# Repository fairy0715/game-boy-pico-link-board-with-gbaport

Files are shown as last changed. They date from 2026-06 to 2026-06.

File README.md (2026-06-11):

# USB TO GAMEBOY LINK CABLE ADAPTER

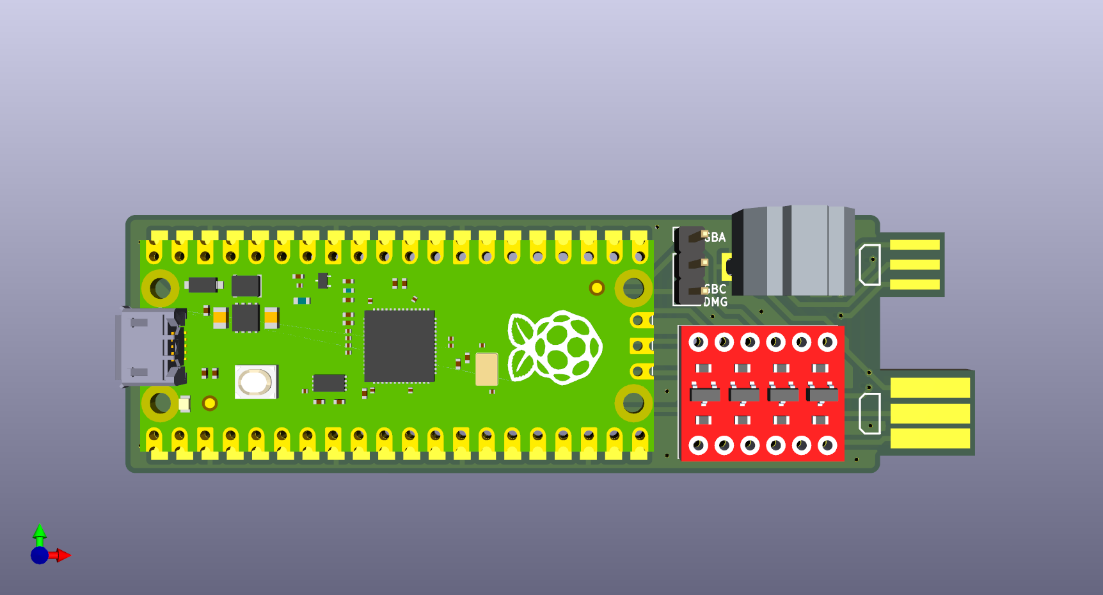
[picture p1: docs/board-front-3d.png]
Board 3D Render


フォーク元の基板にGBA用通信ポートを追加しました、基板を傷めずに接続できます。  
以下はフォーク元のREADMEを追記・修正して作成しています

ライセンスは自作した[libraries/gba_linkport Libraries](libraries/gba_linkport%20Libraries)内のみ[CC0](http://creativecommons.org/publicdomain/zero/1.0/deed.ja)です。  
その他はMITライセンスを引き継いでいます。

Raspberry Pi Pico用のオープンソースUSB-ゲームボーイリンクケーブルアダプタです。入手しやすくはんだ付けしやすい部品で設計されています。

stacksmashing の Gameboy Link adapter に基づいています: https://www.youtube.com/watch?v=KtHu693wE9o

## 回路図

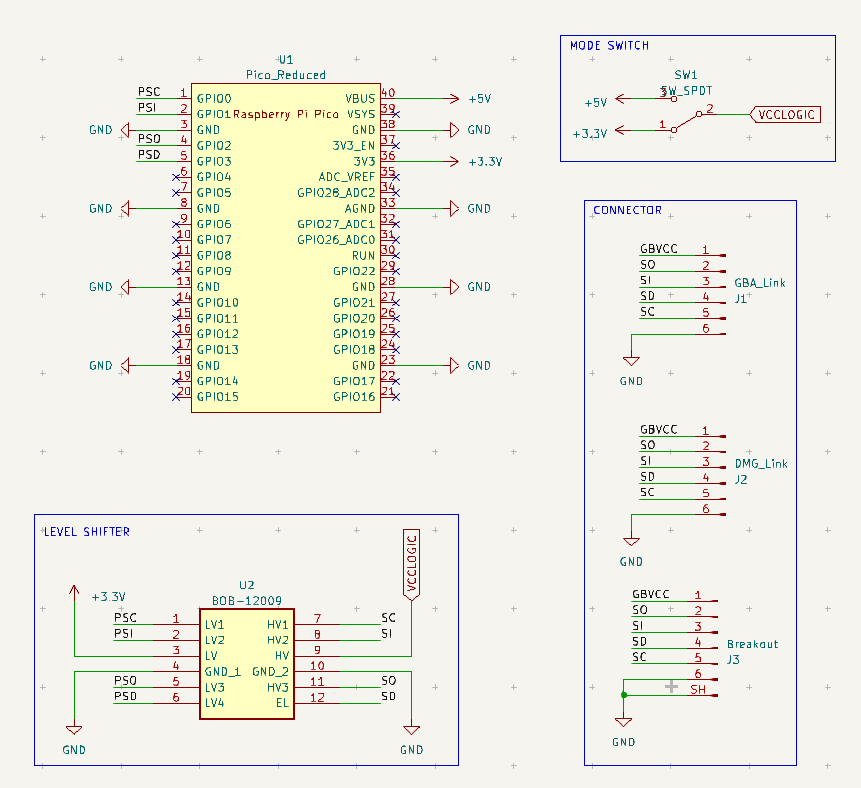
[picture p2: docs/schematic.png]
Schematic


## 部品

|リファレンス|型番|説明|
|---|---|---|
|U1|[Raspberry Pi Pico](https://www.raspberrypi.com/products/raspberry-pi-pico/)|クローン品も互換性あり|
|U2|BOB-12009 [sparkfun](https://www.sparkfun.com/products/12009) [秋月電子（未検証）](https://akizukidenshi.com/catalog/g/g113837/)|Sparkfun 双方向ロジックコンバータ（クローン品も互換性あり）|
|SW1|SS12D00-G3 [amazon](https://www.amazon.com/Tnuocke-Vertical-Position-Switches-SS12D00-G3/dp/B099MRCDG8) [秋月電子](https://akizukidenshi.com/catalog/g/g115707/)|1回路2接点 2.54mmピッチ スライドスイッチ|

SW1 はピンヘッダとジャンパで代用できます

|リファレンス|型番|説明|
|---|---|---|
|SW1|[ピンヘッダ](https://www.amazon.com/dp/B07PKKY8BX)|1x3 2.54mm オスピンヘッダー|
|-|[ジャンパ](https://www.amazon.com/dp/B077957RN7)|2.54mm ジャンパピン、古いマザーボードまたはハードドライブから取り出してください|

添付のリンクは参考用です。同等の部品であればどれでも使用できます。  
秋月電子のレベルシフタは、部品実装面が基板側に来るように配置が必要だと思います。

[テスト済み部品一覧](COMPONENTS.md)

## 基板の注文

基板のデータはリリース内の`gerbers.zip`を使用するか、Kicadファイルから生成してください。[JLCPCB](https://jlcpcb.com/)や[PCBWay](https://www.pcbway.com/)などで注文できます。

ソルダーマスクとシルクスクリーンの色は自由です。  
以下はGBAコネクタを使用せず、直接基板に通信ケーブルを繋ぐ場合の注意点です。

- 基板の厚みは 1.2mm を指定
- 表面処理は ENIG（金メッキ）を推奨

## 基板の組み立て

1. ヤスリなどを使って、基板上のコネクタ部の幅を適切なサイズにカットする
1. Raspberry Pi Picoとレベルシフタモジュールを基板にはんだ付けする（適宜ピンヘッダを使用する）
1. ニッパーで余分なピンを切り落とす
1. スイッチ or ピンヘッダ+ジャンパをはんだ付けする
1. Raspberry Pi Picoにファームウェアを書き込む（[互換性](#互換性) を参照）

## 使い方

GB/GBCソフトの場合はジャンパピンをDMG/GBC側に、GBAソフトの場合はジャンパピンをGBA側に取り付けてください。

>[!WARNING]
>ゲームボーイ/ゲームボーイカラーモードは5Vロジックを使用し、ゲームボーイアドバンスモードは3.3Vロジックを使用することに注意してください。損傷を防ぐため、ジャンパが正しい側に接続されていることを確認してください。

その後 Raspberry Pi Pico を PC に接続し、通信ポート or 基板のコネクタとゲームボーイ（シリーズ）を通信ケーブルで接続してください。

## 互換性

この基板は以下のファームウェアと互換性があります。
- https://github.com/Lorenzooone/gb-link-firmware-reconfigurable （推奨ファームウェア）
- https://github.com/stacksmashing/gb-link-firmware
- https://github.com/stacksmashing/gb-link-printer
- https://github.com/Lorenzooone/PokemonGB_Online_Trades
- https://github.com/dj505/GBPrinterEmu
- https://github.com/Squaresweets/GBPrinter-discord-bot
- https://github.com/KuestenKeks/pc-to-gb-printer

若干の変更を加えることで、以下のような他のファームウェアとも互換性があるはずです。
- https://github.com/untoxa/pico-gb-printer

## 参考

- Raspberry Pi Pico Footprint: https://github.com/ncarandini/KiCad-RP-Pico
- Logic Level Converter (BOB-12009) Footprint: https://www.snapeda.com/parts/BOB-12009/SparkFun%20Electronics/view-part/
- Gameboy Link Connector Footprint: https://github.com/Palmr/gb-link-cable
- 1.2mm PCB Thickness, based on: https://hackaday.io/project/12932-game-link-online/log/43999-received-the-breakout-boards

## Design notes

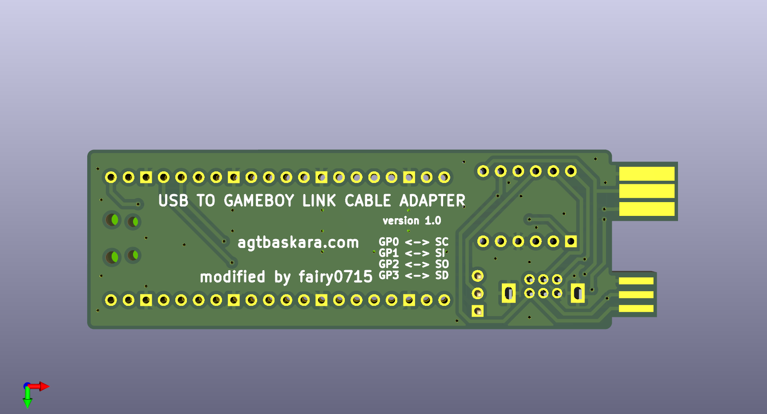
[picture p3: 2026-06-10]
docs/board-back-3d.png

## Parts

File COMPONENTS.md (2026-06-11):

# テスト済みコンポーネント一覧

このページには、本基板でテスト済みのコンポーネントが掲載されています。このページは、私の個人的なテスト結果とコミュニティからのデータに基づいています。

## Raspberry Pi Pico

理論上は、同じピン配置を持つすべてのRaspberry Pi Picoクローンで動作するはずです。

| 互換性 | 画像 | 販売店/データシート | 説明 |
| - | - | - | - |
| あり | PICO | [リンク](https://www.raspberrypi.com/products/raspberry-pi-pico/) | 本家 Raspberry Pi Pico |
| あり | PICO | [リンク](https://www.raspberrypi.com/products/raspberry-pi-pico/) | 本家 Raspberry Pi Pico W |
| あり | PICO | [リンク](https://www.aliexpress.com/item/1005003928558306.html) | RP2040 Lite Black TYPE-C 4M |

## レベルシフタ

質の悪いクローン製品には注意してください。

| 互換性 | 画像 | 販売店/データシート | 説明 |
| - | - | - | - |
| あり | Level Shifter Level Shifter | [sparkfun](https://www.sparkfun.com/products/12009) | Sparkfun製 4チャンネルレベルシフター |
| あり | Level Shifter Level Shifter | | |
| あり | Level Shifter Level Shifter | [Amazon US](https://www.amazon.co.jp/-/en/gp/product/B0CL2R6K26/) | |
| なし | Level Shifter Level Shifter | [Amazon US](https://www.amazon.co.jp/-/en/gp/product/B081RH1P4L) | 薄く、低品質な基板 |
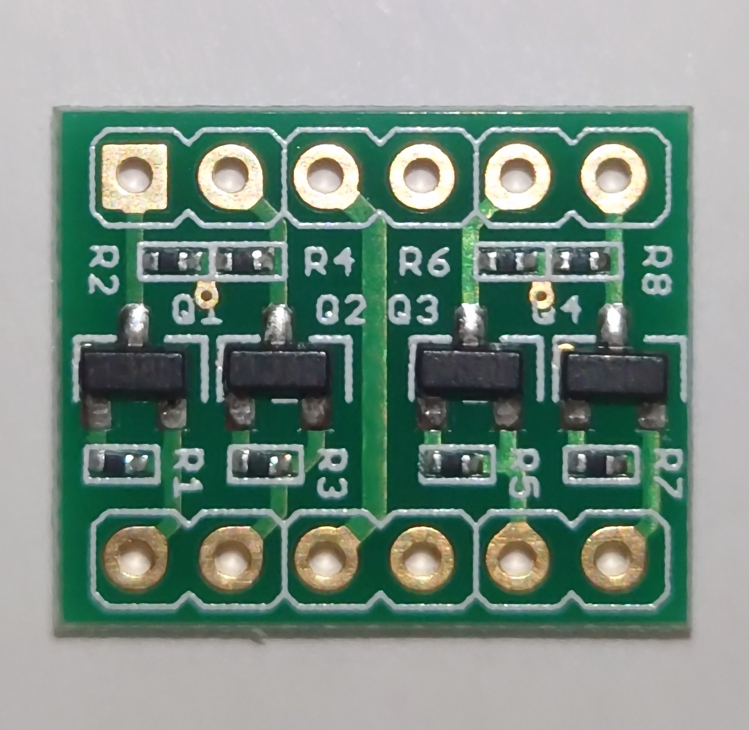
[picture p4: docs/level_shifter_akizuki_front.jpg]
Level Shifter
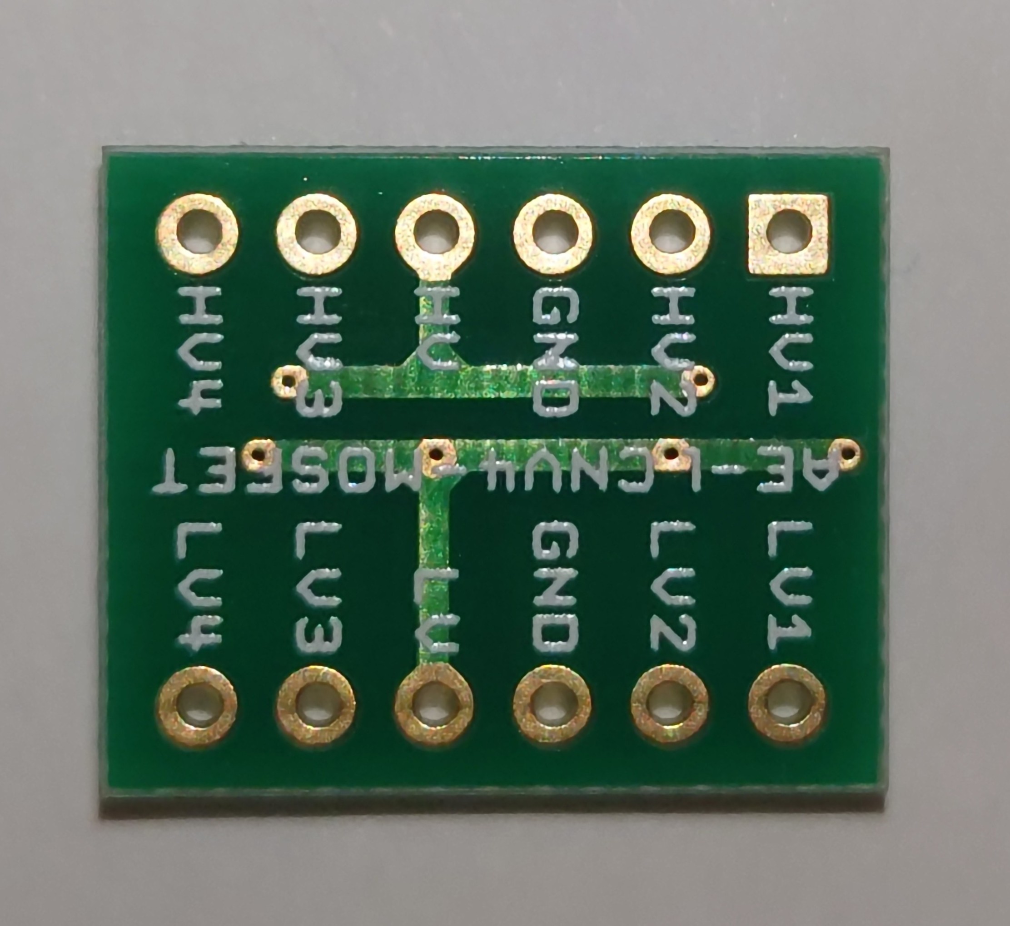
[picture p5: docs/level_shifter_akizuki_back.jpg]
Level Shifter
| あり（未検証） |   | [秋月電子 販売コード:113817](https://akizukidenshi.com/catalog/g/g113837/) | 他とは違い、裏返して本体基板に実装する点に注意 |

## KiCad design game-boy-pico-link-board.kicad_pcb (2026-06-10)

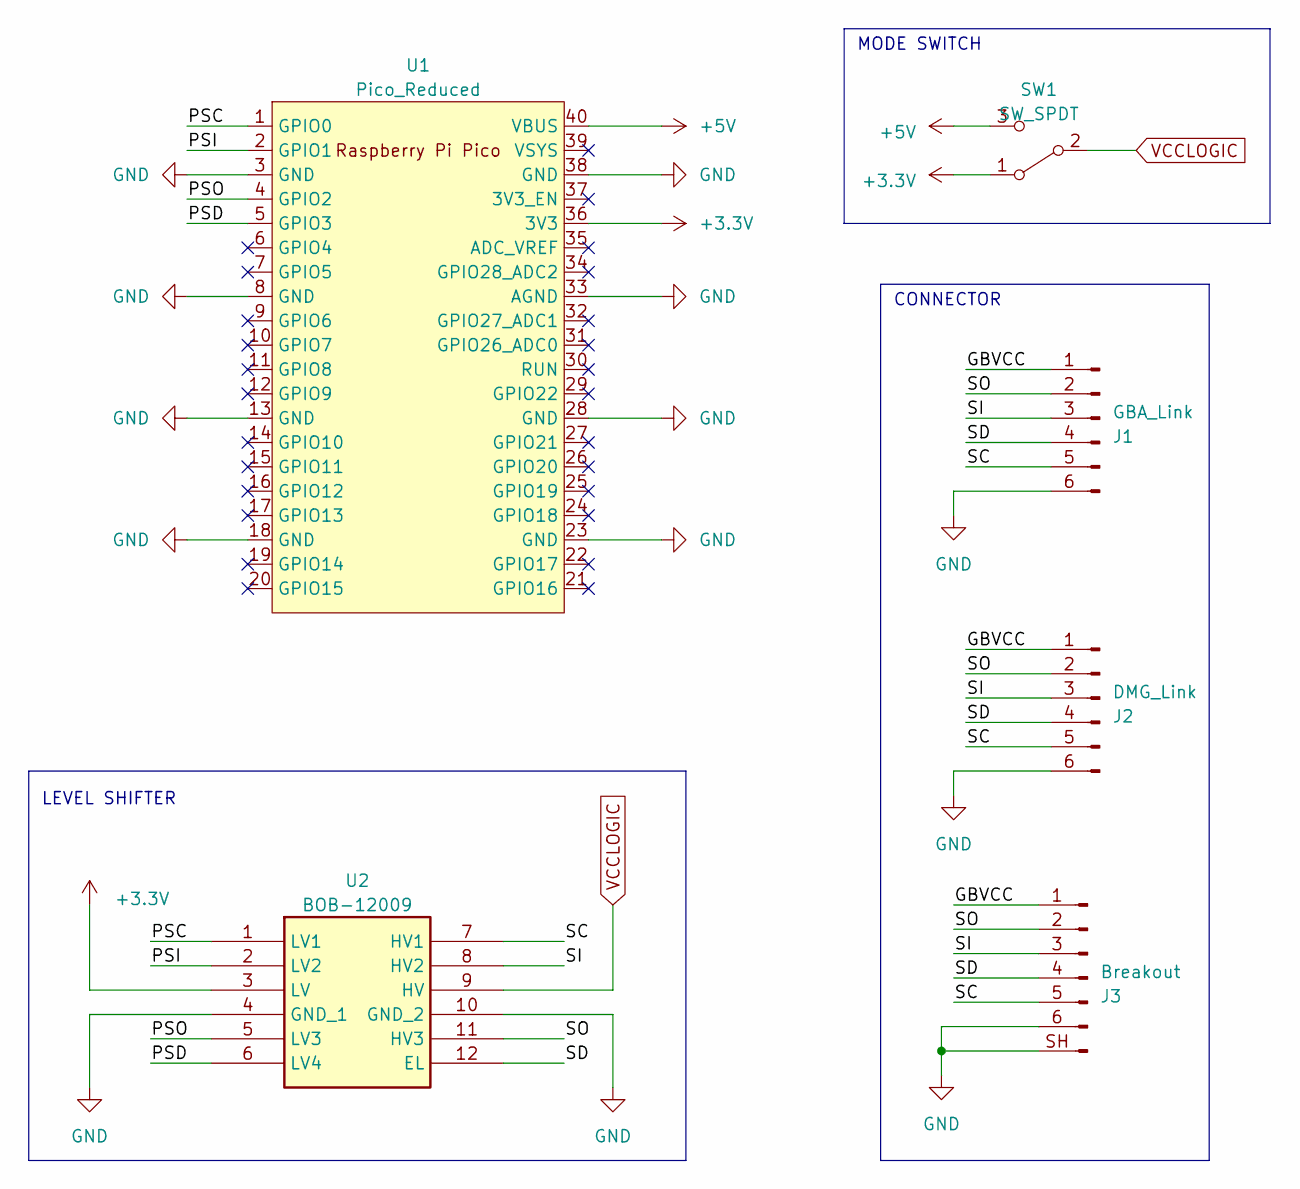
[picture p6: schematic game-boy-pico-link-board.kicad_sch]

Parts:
J1: GBA_Link; gb-link-socket
J2: DMG_Link; dmg-link-socket
J3: Breakout; gba_linkport
SW1: SW_SPDT; PinHeader_1x03_P2.54mm_Vertical
U1: Pico_Reduced; RPi_Pico_SMD_TH_REDUCED
U2: BOB-12009

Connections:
+3.3V: SW1.1 (A), U1.36 (3V3), U2.3 (LV)
+5V: SW1.3 (C), U1.40 (VBUS)
/GBVCC: J1.1, J2.1, J3.1
/PSC: U1.1 (GPIO0), U2.1 (LV1)
/PSD: U1.5 (GPIO3), U2.6 (LV4)
/PSI: U1.2 (GPIO1), U2.2 (LV2)
/PSO: U1.4 (GPIO2), U2.5 (LV3)
/SC: J1.5, J2.5, J3.5, U2.7 (HV1)
/SD: J1.4, J2.4, J3.4, U2.12 (EL)
/SI: J1.3, J2.3, J3.3, U2.8 (HV2)
/SO: J1.2, J2.2, J3.2, U2.11 (HV3)
GND: J1.6, J2.6, J3.6, J3.SH (Pin_7), U1.3 (GND), U1.8 (GND), U1.13 (GND), U1.18 (GND), U1.23 (GND), U1.28 (GND), U1.33 (AGND), U1.38 (GND), U2.4 (GND_1), U2.10 (GND_2)
VCCLOGIC: SW1.2 (B), U2.9 (HV)

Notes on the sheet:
LEVEL SHIFTER
MODE SWITCH
CONNECTOR

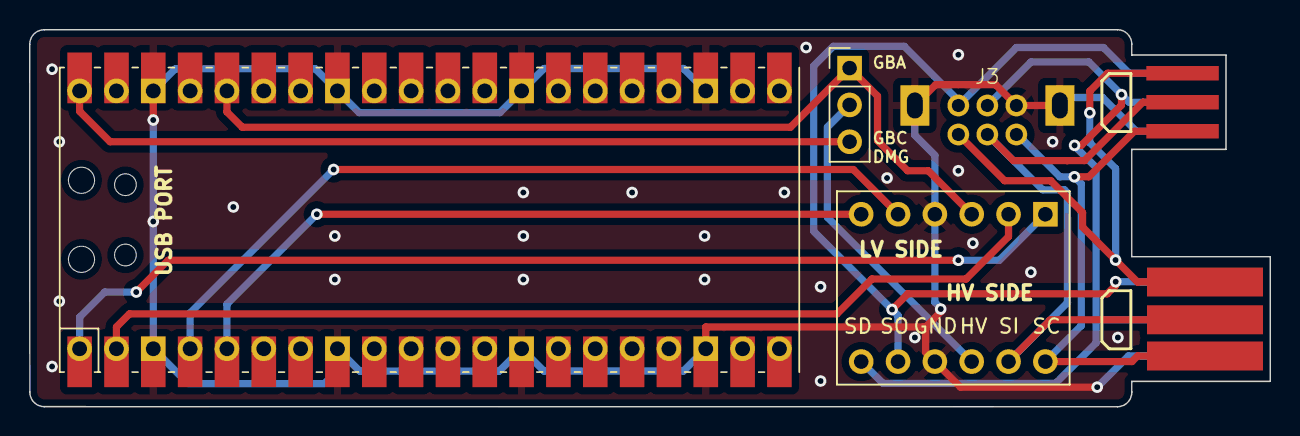
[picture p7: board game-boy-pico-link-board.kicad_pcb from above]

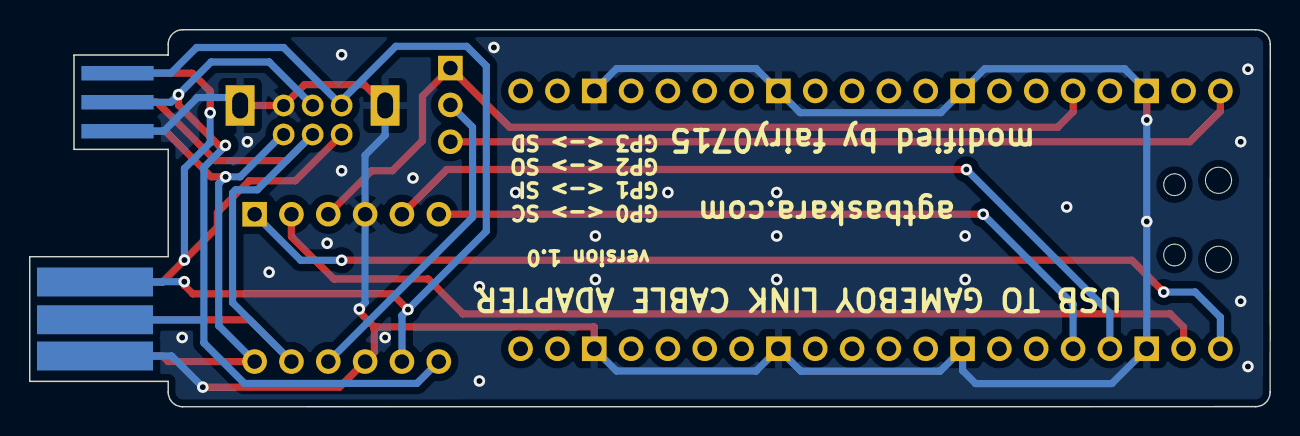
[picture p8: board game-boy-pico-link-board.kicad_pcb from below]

Board: 2 copper layers, 85.5 x 26.0 mm, 6 parts (2 on the bottom side), 13 nets.

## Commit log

2026-06-11 readmeを修正
2026-06-11 COMPONENTS.mdを翻訳・追記
